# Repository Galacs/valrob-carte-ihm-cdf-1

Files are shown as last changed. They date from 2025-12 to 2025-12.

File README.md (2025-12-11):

# Carte IHM CDF 1

ESP32-S3-WROOM-1 HM interface card

## IC List

- ESP32-S3-WROOM-1 (Main MCU Module)
- TLV757P (MCU 3v3 LDO)
- SSD1315 (128x64 OLED display)
- 3x WS2812B (RGB status leds)
- 74HC14 (HEX Schmitt trigger)

## Top preview



## Preview 3d render



## Pin definitions

```c
#define DIP_A_PIN 14
#define DIP_B_PIN 21
#define DIP_C_PIN 47
#define DIP_D_PIN 48

#define STARTER_PIN 11

#define TEAM_A_PIN 13
#define TEAM_B_PIN 12

#define UP_BTN_PIN 10
#define DOWN_BTN_PIN 17
#define CONF_BTN_PIN 18

#define OLED_I2C_SCL 3
#define OLED_I2C_SDA 9

#define RBG_LEDS_PIN 45

#define BATT_SENSE_PIN 2
```

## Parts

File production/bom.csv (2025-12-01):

Designator | Footprint | Quantity | Value | LCSC Part #
C1, C2, C6 | 0603 | 3 | 22u | C59461
C10, C11, C12, C13, C4, C7, C8, C9 | 0402 | 8 | 0u1 | C1525
C3 | 0603 | 1 | 10u | C19702
C5 | 0402 | 1 | 1u | C52923
D1, D3, D5 | LED_WS2812B_PLCC4_5.0x5.0mm_P3.2mm | 3 | WS2812B | C22371521
D10, D11, D12, D13, D14, D15, D16, D17, D18 | Diode_DFN1006 | 9 | H5VU10U | C22395519
D2, D4 | D_SMA | 2 | D_Schottky | C22452
D6 | 0805 | 1 | GREEN | C2297
D7 | D_SMB | 1 | P6SMB6.8CA/TR13 | C78395
D8 | D_SOD-123 | 1 | BZT52B3V3 | C19077392
D9 | D_SMA | 1 | SMAJ12A | C19077531
J1 | USB_C_Receptacle_HRO_TYPE-C-31-M-12 | 1 | USB_C_Receptacle_USB2.0_14P | C393939
R1, R2, R3 | 0402 | 3 | 5k1 | C25905
R10, R11, R12, R13, R14, R15, R22, R23, R5, R6, R7 | 0402 | 11 | 10k | C25744
R16, R17, R18, R19, R20, R21 | 0402 | 6 | 1k | C11702
R4 | 0603 | 1 | 1k8 | C4177
R8, R9 | 0402 | 2 | 22 | C25092
SW1, SW2 | SW_SPST_TS-1088-xR020 | 2 | SW_Push | C720477
U1 | SOT-23-5 | 1 | TLV75733PDBV | C485517
U5 | SOIC-14_3.9x8.7mm_P1.27mm | 1 | 74HC14 | C5605

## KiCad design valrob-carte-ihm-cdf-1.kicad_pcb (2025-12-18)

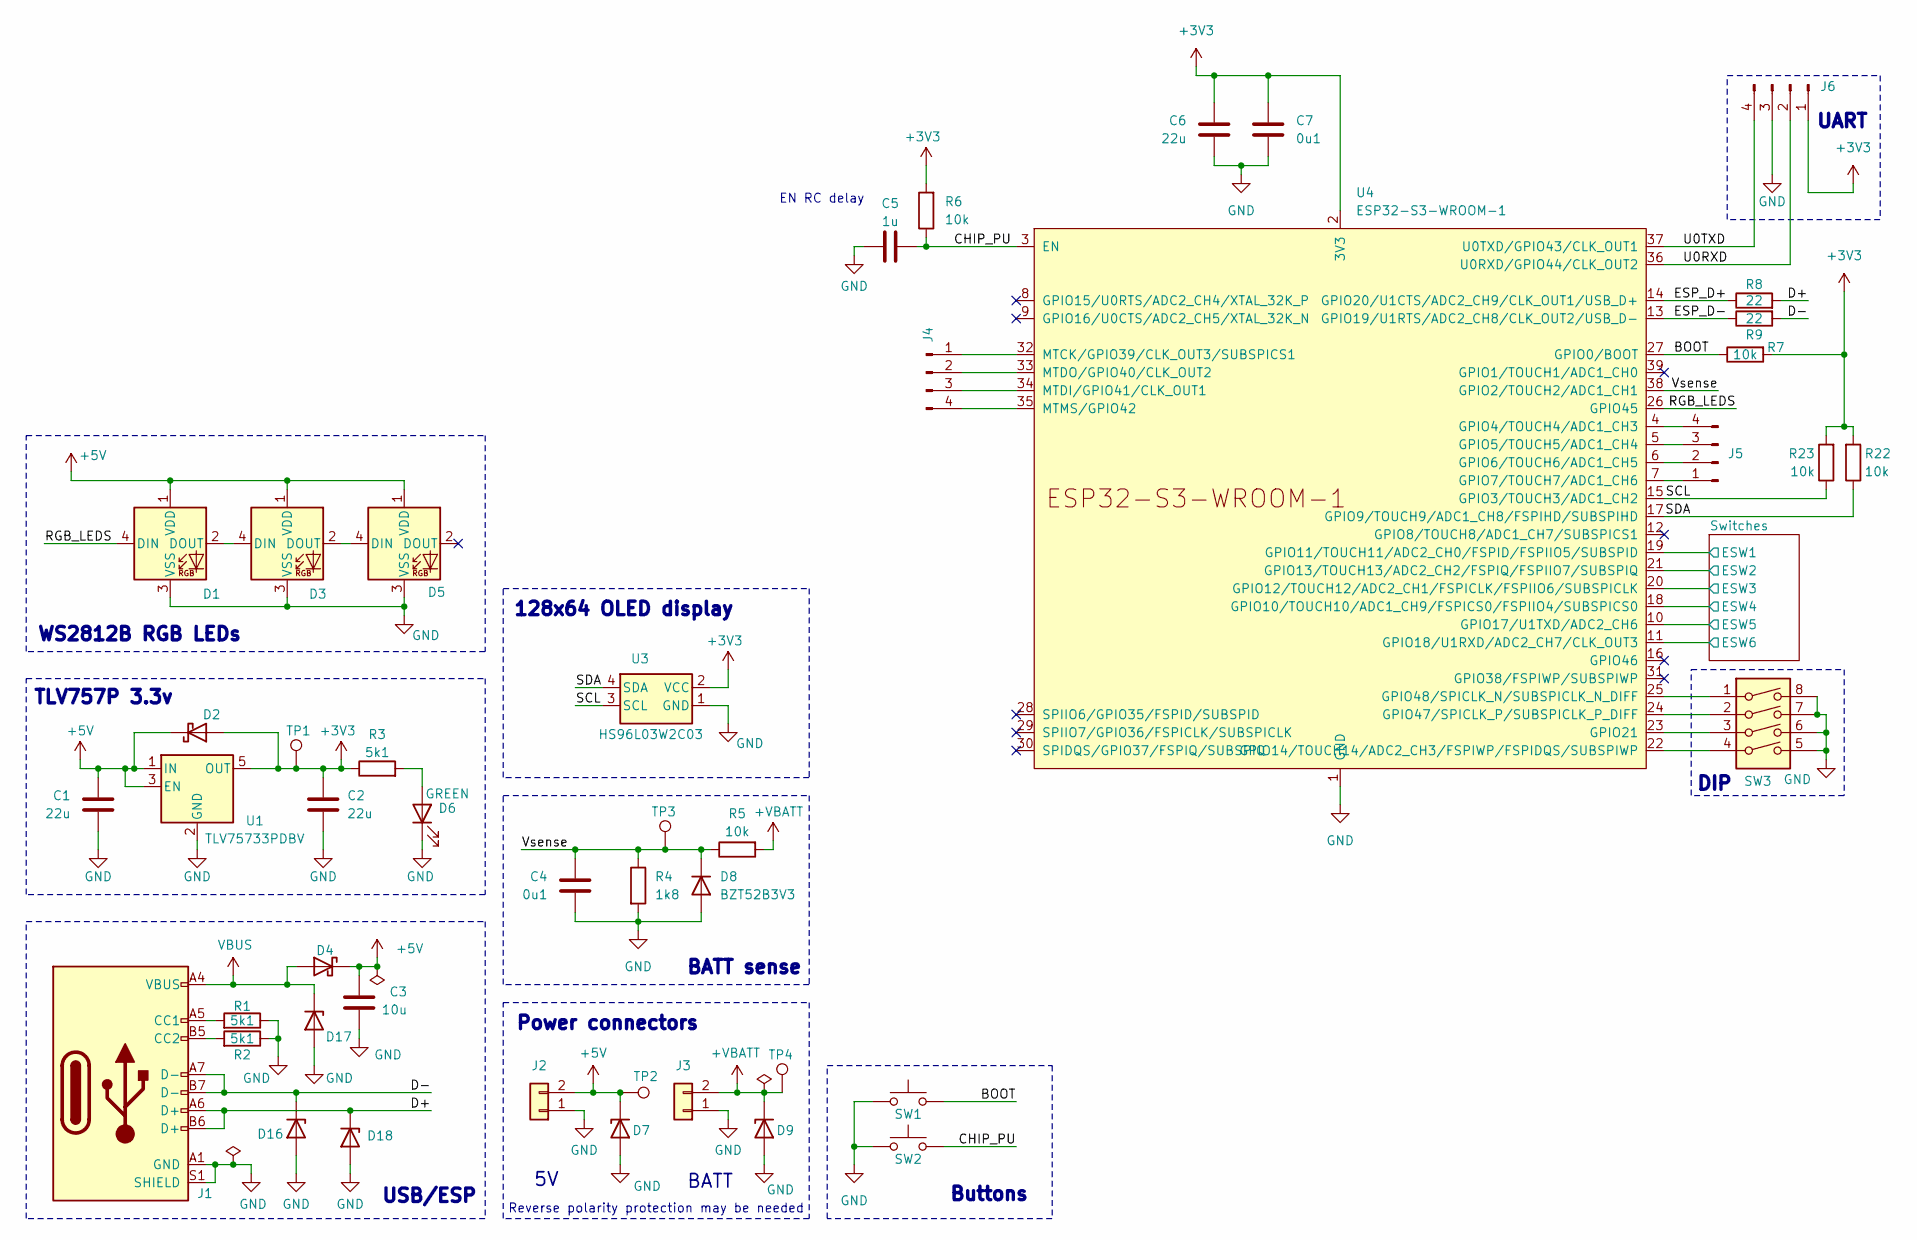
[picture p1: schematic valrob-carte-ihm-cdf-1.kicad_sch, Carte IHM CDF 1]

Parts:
C1, C2, C6: 22u; C_0603_1608Metric; Manufacturer Part Number CL10A226MQ8NRNC; JLCPCB Part # C59461
C3: 10u; C_0603_1608Metric; Manufacturer Part Number CL10A106KP8NNNC; JLCPCB Part # C19702
C4, C7: 0u1; C_0402_1005Metric; Manufacturer Part Number CL05B104KO5NNNC; JLCPCB Part # C1525
C5: 1u; C_0402_1005Metric; Manufacturer Part Number CL05A105KA5NQNC; JLCPCB Part # C52923
D1, D3, D5: WS2812B; LED_WS2812B_PLCC4_5.0x5.0mm_P3.2mm; Manufacturer Part Number WS2812B-HS01/W; JLCPCB Part # C22371521
D2, D4: D_Schottky; D_SMA; Manufacturer Part Number SS54; JLCPCB Part # C22452
D6: GREEN; LED_0805_2012Metric; Manufacturer Part Number KT-0805G; JLCPCB Part # C2297
D7: P6SMB6.8CA/TR13; D_SMB; Manufacturer Part Number P6SMB6.8CA/TR13; JLCPCB Part # C78395
D8: BZT52B3V3; D_SOD-123; Manufacturer Part Number BZT52B3V3; JLCPCB Part # C19077392
D9: SMAJ12A; D_SMA; Manufacturer Part Number SMAJ12A; JLCPCB Part # C19077531
D16, D17, D18: H5VU10U; Diode_DFN1006; Manufacturer Part Number H5VU10U; JLCPCB Part # C22395519
J1: USB_C_Receptacle_USB2.0_14P; USB_C_Receptacle_HRO_TYPE-C-31-M-12; Manufacturer Part Number TYPE-C16PIN; JLCPCB Part # C393939
J2, J3: Conn_01x02; JST_XH_S2B-XH-A_1x02_P2.50mm_Horizontal
J4, J5, J6: Conn_01x04_Pin; PinHeader_1x04_P2.54mm_Vertical
R1, R2, R3: 5k1; R_0402_1005Metric; Manufacturer Part Number 0402WGF5101TCE; JLCPCB Part # C25905
R4: 1k8; R_0603_1608Metric; Manufacturer Part Number 0603WAF1801T5E; JLCPCB Part # C4177
R5, R6, R7, R22, R23: 10k; R_0402_1005Metric; Manufacturer Part Number 0402WGF1002TCE; JLCPCB Part # C25744
R8, R9: 22; R_0402_1005Metric; Manufacturer Part Number 0402WGF220JTCE; JLCPCB Part # C25092
SW1, SW2: SW_Push; SW_SPST_TS-1088-xR020; Manufacturer Part Number TS-1088-AR02016; JLCPCB Part # C720477
SW3: SW_DIP_x04; SW_DIP_SPSTx04_Slide_9.78x12.34mm_W7.62mm_P2.54mm
TP1, TP2, TP3, TP4: TestPoint; TestPoint_Pad_D2.0mm
U1: TLV75733PDBV; SOT-23-5; Manufacturer Part Number TLV75733PDBVR; JLCPCB Part # C485517
U3: HS96L03W2C03
U4: ESP32-S3-WROOM-1

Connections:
+3V3: C2.2, C6.1, C7.1, D2.2 (A), J6.1, R3.1, R6.2, R7.2, R22.2, R23.2, TP1.1, U1.5 (OUT), U3.2 (VCC), U4.2 (3V3); also elsewhere on the board
+5V: C1.2, C3.1, D1.1 (VDD), D2.1 (K), D3.1 (VDD), D4.1 (K), D5.1 (VDD), D7.1 (K), J2.2, TP2.1, U1.1 (IN), U1.3 (EN)
+VBATT: D9.1 (K), J3.2, R5.2, TP4.1
/BOOT: R7.1, SW1.2, U4.27 (GPIO0/BOOT)
/CHIP_PU: C5.2, R6.1, SW2.2, U4.3 (EN)
/D+: D18.1 (K), J1.A6 (D+), J1.B6 (D+), R8.2
/D-: D16.1 (K), J1.A7 (D-), J1.B7 (D-), R9.2
/ESP_D+: R8.1, U4.14 (GPIO20/U1CTS/ADC2_CH9/CLK_OUT1/USB_D+)
/ESP_D-: R9.1, U4.13 (GPIO19/U1RTS/ADC2_CH8/CLK_OUT2/USB_D-)
/RGB_LEDS: D1.4 (DIN), U4.26 (GPIO45)
/SCL: R23.1, U3.3 (SCL), U4.15 (GPIO3/TOUCH3/ADC1_CH2)
/SDA: R22.1, U3.4 (SDA), U4.17 (GPIO9/TOUCH9/ADC1_CH8/FSPIHD/SUBSPIHD)
/Switches/ESW1: U4.19 (GPIO11/TOUCH11/ADC2_CH0/FSPID/FSPIIO5/S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); also elsewhere on the board
/Switches/ESW2: U4.21 (GPIO13/TOUCH13/ADC2_CH2/FSPIQ/FSPIIO7/S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); also elsewhere on the board
/Switches/ESW3: U4.20 (GPIO12/TOUCH12/ADC2_CH1/FSPICLK/FSPIIO6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); also elsewhere on the board
/Switches/ESW4: U4.18 (GPIO10/TOUCH10/ADC1_CH9/FSPICS0/FSPIIO4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); also elsewhere on the board
/Switches/ESW5: U4.10 (GPIO17/U1TXD/ADC2_CH6); also elsewhere on the board
/Switches/ESW6: U4.11 (GPIO18/U1RXD/ADC2_CH7/CLK_OUT3); also elsewhere on the board
/U0RXD: J6.2, U4.36 (U0RXD/GPIO44/CLK_OUT2)
/U0TXD: J6.4, U4.37 (U0TXD/GPIO43/CLK_OUT1)
/Vsense: C4.1, D8.1 (K), R4.1, R5.1, TP3.1, U4.38 (GPIO2/TOUCH2/ADC1_CH1)
GND: C1.1, C2.1, C3.2, C4.2, C5.1, C6.2, C7.2, D1.3 (VSS), D3.3 (VSS), D5.3 (VSS), D6.1 (K), D7.2 (A), D8.2 (A), D9.2 (A), D16.2 (A), D17.2 (A), D18.2 (A), J1.A1 (GND), J1.A12 (GND), J1.B1 (GND), J1.B12 (GND), J1.S1 (SHIELD), J2.1, J3.1, J6.3, R1.1, R2.1, R4.2, SW1.1, SW2.1, SW3.5, SW3.6, SW3.7, SW3.8, U1.2 (GND), U3.1 (GND), U4.1 (GND), U4.40 (GND), U4.41 (GND); also elsewhere on the board
unnamed: D1.2 (DOUT), D3.4 (DIN)
unnamed: D3.2 (DOUT), D5.4 (DIN)
unnamed: D6.2 (A), R3.2
unnamed: J1.A5 (CC1), R1.2
unnamed: J1.B5 (CC2), R2.2
unnamed: J4.1, U4.32 (MTCK/GPIO39/CLK_OUT3/SUBSPICS1)
unnamed: J4.2, U4.33 (MTDO/GPIO40/CLK_OUT2)
unnamed: J4.3, U4.34 (MTDI/GPIO41/CLK_OUT1)
unnamed: J4.4, U4.35 (MTMS/GPIO42)
unnamed: J5.1, U4.7 (GPIO7/TOUCH7/ADC1_CH6)
unnamed: J5.2, U4.6 (GPIO6/TOUCH6/ADC1_CH5)
unnamed: J5.3, U4.5 (GPIO5/TOUCH5/ADC1_CH4)
unnamed: J5.4, U4.4 (GPIO4/TOUCH4/ADC1_CH3)
unnamed: SW3.4, U4.22 (GPIO14/TOUCH14/ADC2_CH3/FSPIWP/FSPIDQS/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)
unnamed: SW3.3, U4.23 (GPIO21)
unnamed: SW3.2, U4.24 (GPIO47/SPICLK_P/SUBSPICLK_P_DIFF)
unnamed: SW3.1, U4.25 (GPIO48/SPICLK_N/SUBSPICLK_N_DIFF)
VBUS: D4.2 (A), D17.1 (K), J1.A4 (VBUS), J1.A9 (VBUS), J1.B4 (VBUS), J1.B9 (VBUS)

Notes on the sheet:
TLV757P 3.3v
Buttons
WS2812B RGB LEDs
Power connectors
DIP
EN RC delay
USB/ESP
BATT sense
UART
Reverse polarity protection may be needed
BATT
128x64 OLED display

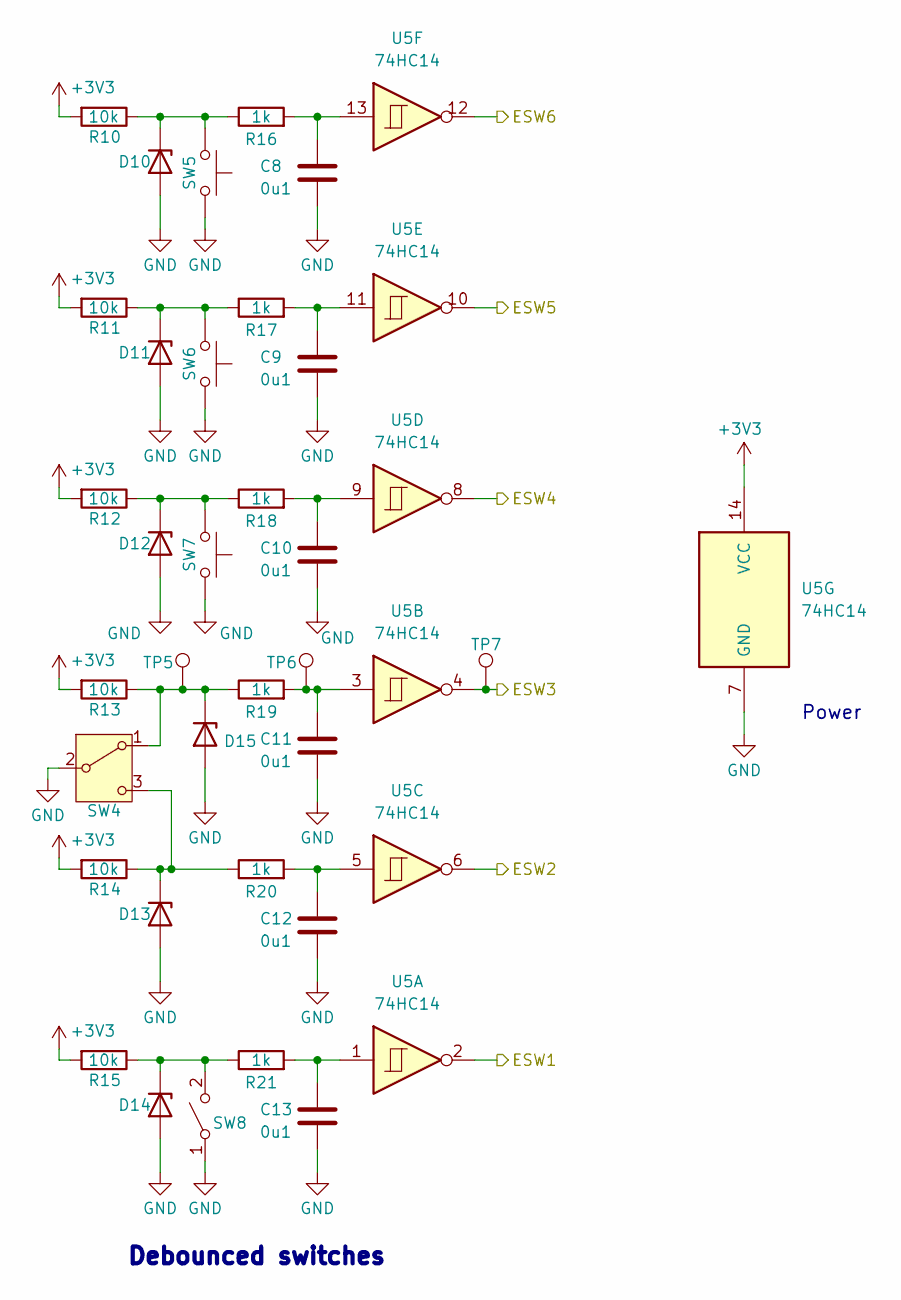
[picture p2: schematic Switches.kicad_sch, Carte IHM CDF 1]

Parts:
C8, C9, C10, C11, C12, C13: 0u1; C_0402_1005Metric; Manufacturer Part Number CL05B104KO5NNNC; JLCPCB Part # C1525
D10, D11, D12, D13, D14, D15: H5VU10U; Diode_DFN1006; Manufacturer Part Number H5VU10U; JLCPCB Part # C22395519
R10, R11, R12, R13, R14, R15: 10k; R_0402_1005Metric; Manufacturer Part Number 0402WGF1002TCE; JLCPCB Part # C25744
R16, R17, R18, R19, R20, R21: 1k; R_0402_1005Metric; Manufacturer Part Number 0402WGF1001TCE; JLCPCB Part # C11702
SW4: SW_SPDT; MT-0-102-A101-M200-RS
SW5, SW6, SW7: SW_Push; SW_PUSH_6mm_H7.3mm
SW8: SW_SPST; PinHeader_1x02_P2.54mm_Vertical
TP5, TP6, TP7: TestPoint; TestPoint_Pad_D2.0mm
U5: 74HC14; SOIC-14_3.9x8.7mm_P1.27mm; Manufacturer Part Number 74HC14D,653; JLCPCB Part # C5605

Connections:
+3V3: R10.2, R11.2, R12.2, R13.2, R14.2, R15.2, U5.14 (VCC); also elsewhere on the board
/Switches/ESW1: U5.2; also elsewhere on the board
/Switches/ESW2: U5.6; also elsewhere on the board
/Switches/ESW3: TP7.1, U5.4; also elsewhere on the board
/Switches/ESW4: U5.8; also elsewhere on the board
/Switches/ESW5: U5.10; also elsewhere on the board
/Switches/ESW6: U5.12; also elsewhere on the board
GND: C8.2, C9.2, C10.2, C11.2, C12.2, C13.2, D10.2 (A), D11.2 (A), D12.2 (A), D13.2 (A), D14.2 (A), D15.2 (A), SW4.2 (B), SW5.1, SW6.1, SW7.1, SW8.1 (A), U5.7 (GND); also elsewhere on the board
unnamed: C8.1, R16.2, U5.13
unnamed: C9.1, R17.2, U5.11
unnamed: C10.1, R18.2, U5.9
unnamed: C11.1, R19.2, TP6.1, U5.3
unnamed: C12.1, R20.2, U5.5
unnamed: C13.1, R21.2, U5.1
unnamed: D10.1 (K), R10.1, R16.1, SW5.2
unnamed: D11.1 (K), R11.1, R17.1, SW6.2
unnamed: D12.1 (K), R12.1, R18.1, SW7.2
unnamed: D13.1 (K), R14.1, R20.1, SW4.3 (C)
unnamed: D14.1 (K), R15.1, R21.1, SW8.2 (B)
unnamed: D15.1 (K), R13.1, R19.1, SW4.1 (A), TP5.1

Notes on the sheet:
Debounced switches
Power

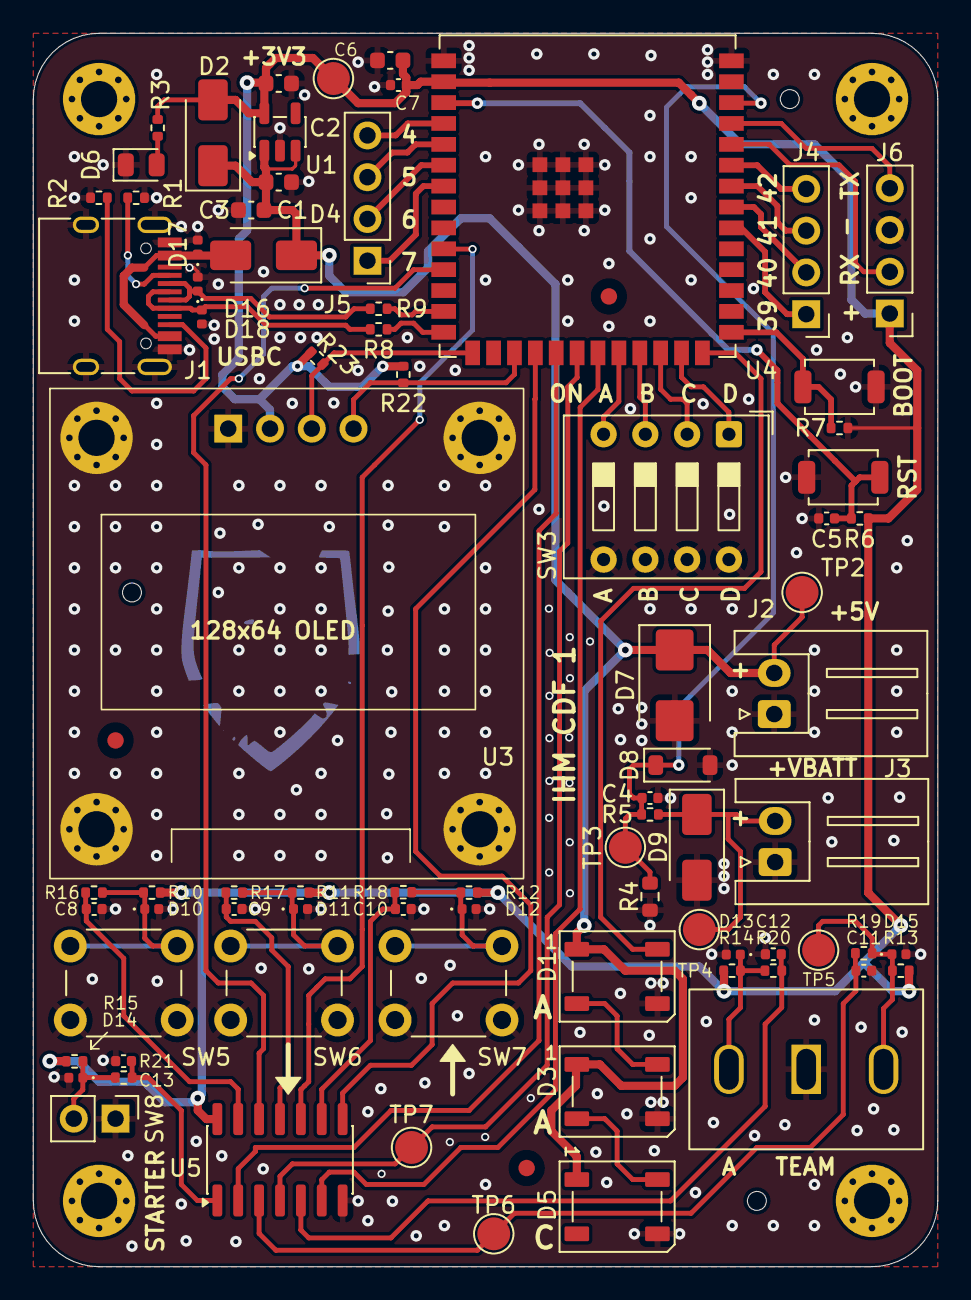
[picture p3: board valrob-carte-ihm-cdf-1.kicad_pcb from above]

Board: 2 copper layers, 55.0 x 75.0 mm, 79 parts (0 on the bottom side), 52 nets.

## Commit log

2025-11-24 schem: import ESP32-S3-WROOM-1 from valrob-carte-moteur-cdf-1
    [valrob-carte-ihm-cdf-1.kicad_sch]
2025-11-24 schem: import USBC from valrob-carte-moteur-cdf-1
    [valrob-carte-ihm-cdf-1.kicad_sch]
2025-11-24 schem: add TLV757P 3.3v LDO
    [valrob-carte-ihm-cdf-1.kicad_sch]
2025-11-24 schem: import BOOT and RST buttons from valrob-carte-moteur-cdf-1
    [valrob-carte-ihm-cdf-1.kicad_sch]
2025-11-24 schem: add VBATT voltage sense
    [valrob-carte-ihm-cdf-1.kicad_sch]
2025-11-24 schem: add dip switches
    [valrob-carte-ihm-cdf-1.kicad_sch]
2025-11-24 schem: add debounced switches
    [Switches.kicad_sch, valrob-carte-ihm-cdf-1.kicad_sch]
2025-11-24 schem: add WS2812B addressable RGB LEDs
    [valrob-carte-ihm-cdf-1.kicad_sch]
2025-11-24 schem: add HS96L03W2C03 OLED display
    [valrob-carte-ihm-cdf-1.kicad_sch]
2025-11-24 schem: add spare GPIOs
    [valrob-carte-ihm-cdf-1.kicad_sch]
2025-11-24 schem: add switches footprints
    [Switches.kicad_sch, valrob-carte-ihm-cdf-1.kicad_sch]
2025-11-24 schem: add test points
    [Switches.kicad_sch, valrob-carte-ihm-cdf-1.kicad_sch]
2025-11-24 schem: add no connects
    [valrob-carte-ihm-cdf-1.kicad_sch]
2025-11-24 schem: connect i2c to MCU
    [valrob-carte-ihm-cdf-1.kicad_sch]
2025-11-24 schem: run and fix ERC
    [valrob-carte-ihm-cdf-1.kicad_sch]
2025-11-24 schem: add title
    [Switches.kicad_sch, valrob-carte-ihm-cdf-1.kicad_sch]
2025-11-24 schem: reannotate
    [Switches.kicad_sch, valrob-carte-ihm-cdf-1.kicad_sch]
2025-11-24 schem: assign footprints
    [Switches.kicad_sch, valrob-carte-ihm-cdf-1.kicad_sch]
2025-11-24 schem: add part numbers to BOM
    [Switches.kicad_sch, valrob-carte-ihm-cdf-1.kicad_sch]
2025-11-24 pcb: create file and import stackup
    [valrob-carte-ihm-cdf-1.kicad_pcb]
2025-11-24 pcb: import components from schematic
    [valrob-carte-ihm-cdf-1.kicad_pcb]
2025-11-24 pcb: add missing 3d models
    [valrob-carte-ihm-cdf-1.kicad_pcb]
2025-11-24 pcb: add initial rough placement
    [valrob-carte-ihm-cdf-1.kicad_pcb, valrob-carte-ihm-cdf-1.kicad_sch]
2025-11-24 pcb: add layout refinement and board outline
    [Switches.kicad_sch, valrob-carte-ihm-cdf-1.kicad_pcb]
2025-11-24 pcb: add M2 mounting holes
    [valrob-carte-ihm-cdf-1.kicad_pcb]
2025-11-24 pcb: add fiducials and tooling holes
    [valrob-carte-ihm-cdf-1.kicad_pcb]
2025-11-24 pcb: refine layout
    [Switches.kicad_sch, valrob-carte-ihm-cdf-1.kicad_pcb]
2025-11-24 pcb: add ground planes
    [valrob-carte-ihm-cdf-1.kicad_pcb]
2025-11-24 pcb: add gnd vias
    [valrob-carte-ihm-cdf-1.kicad_pcb]
2025-11-24 pcb: place grid and drill origin
    [valrob-carte-ihm-cdf-1.kicad_pcb]
2025-11-24 pcb: add USB routing
    [valrob-carte-ihm-cdf-1.kicad_pcb]
2025-11-24 pcb: add UART routing
    [valrob-carte-ihm-cdf-1.kicad_pcb, valrob-carte-ihm-cdf-1.kicad_sch]
2025-11-24 pcb: add I2C display routing
    [valrob-carte-ihm-cdf-1.kicad_pcb]
2025-11-24 pcb: add display buttons routing
    [valrob-carte-ihm-cdf-1.kicad_pcb, valrob-carte-ihm-cdf-1.kicad_sch]
2025-11-24 pcb: add toggle switch routing
    [valrob-carte-ihm-cdf-1.kicad_pcb, valrob-carte-ihm-cdf-1.kicad_sch]
2025-11-24 pcb: add DIP switches routing
    [valrob-carte-ihm-cdf-1.kicad_pcb, valrob-carte-ihm-cdf-1.kicad_sch]
2025-11-24 pcb: add RGB leds routing
    [valrob-carte-ihm-cdf-1.kicad_pcb]
2025-11-24 pcb: add spare GPIO routing
    [valrob-carte-ihm-cdf-1.kicad_pcb]
2025-11-24 pcb: add 3V3 power routing
    [valrob-carte-ihm-cdf-1.kicad_pcb]
2025-11-24 pcb: add 5V power routing
    [valrob-carte-ihm-cdf-1.kicad_pcb]
2025-11-24 pcb: add RST and BOOT btns routing
    [valrob-carte-ihm-cdf-1.kicad_pcb]
2025-11-24 pcb(silkscreen): clean up reference designators
    [valrob-carte-ihm-cdf-1.kicad_pcb]
2025-11-24 pcb: add stitching vias
    [valrob-carte-ihm-cdf-1.kicad_pcb]
2025-11-24 pcb(silkscreen): add company logo
    [valrob-carte-ihm-cdf-1.kicad_pcb]
2025-11-25 switch ST usb ESD to H5VU10U tvs diodes
    [valrob-carte-ihm-cdf-1.kicad_pcb, valrob-carte-ihm-cdf-1.kicad_sch]
2025-11-25 pcb(silkscreen): improve user txt
    [valrob-carte-ihm-cdf-1.kicad_pcb]
2025-11-25 pcb(silkscreen): refine
    [valrob-carte-ihm-cdf-1.kicad_pcb]
2025-11-25 pcb: add title
    [valrob-carte-ihm-cdf-1.kicad_pcb]
2025-11-25 add production files
    [valrob-carte-ihm-cdf-1.kicad_pcb, valrob-carte-ihm-cdf-1.kicad_sch]
2025-11-30 regenerate production files
    [bom.csv, designators.csv, positions.csv]
2025-12-01 pcb/schem: add missing i2c external pullups
    [valrob-carte-ihm-cdf-1.kicad_pcb, valrob-carte-ihm-cdf-1.kicad_sch]
2025-12-05 docs: add pin definitions to readme
2025-12-18 pcb/schem: fix BOOT pullup
    [valrob-carte-ihm-cdf-1.kicad_pcb, valrob-carte-ihm-cdf-1.kicad_sch]
